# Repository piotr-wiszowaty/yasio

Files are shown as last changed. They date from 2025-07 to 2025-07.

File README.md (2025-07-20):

YASIO
=====

Yet another [Atari XL/XE](http://en.wikipedia.org/wiki/Atari_8-bit_family) SIO
floppy drive emulator - Yet-Another-SIO.

Features
--------

* Handles ATR and Atari executable files.
* Files stored on a micro-SD FAT32-formatted card.
* Works at speeds up to 115200 BPS.
* Controlled via a WWW browser via WiFi connection.
* Works in WiFi access point or station mode.

Hardware
--------

* Based on an ESP32-S3 devboard.
* Fits into a USB3 device enclosure.

Programming & Asembly
---------------------

Prerequisities:

* [xasm](https://github.com/pfusik/xasm)
* [foco65](https://github.com/piotr-wiszowaty/foco65)
* [PlatformIO](https://platformio.org)

0. Solder all of the components to the PCB.
1. Compile bootloader (optional): `bootloader/generate-bootloader.sh`.
2. Compile setup program: `setup/build.sh`.
3. Connect the device via USB-C cable to a PC (do not connect it to an Atari
   computer yet).
4. Flash the firmware by executing `pio run -e 0 -t upload` in `uc`
   subdirectory.
5. Disconnect the device from Atari computer; put the device in the enclosure.
   Three cutouts in the enclosure are required - for the USB socket, for the
   setup button and for the SIO cable. Note that the enclosure already has a
   hole allowing insertion/ejection of the SD card.

Usage
-----

### SD card preparation

Before turning on the device prepare an SD card - write configuration file
(`setup/yasio.conf`) and setup program (`setup/yasio_setup.xex`) to the root
directory of the SD card filesystem.

The configuration file contents may be prepared beforehand by using a text
editor or setup using the setup program. The setup program is 'inserted' into
`D1` drive by holding the setup button when turning on the device or by
pressing the setup button when the device is working and rebooting the Atari
computer.

### Configuration

Configuration file `yasio.conf` is an ASCII text file with LF-terminated lines.
Each line consists one configuration entry. Each entry starts with an entry key
followed by `:` character and (optional) entry value.
Available configuration entries and :

* `D1`, `D2`, `D3`, `D4` - path to file 'inserted' into appropriate drive;
  e.g.: `D1:demo/Drunk Chessboard.atr`
* `MO` - work mode; available values: `Station`, `AccessPoint`
* `AP` - WiFi access point parameters: SSID, password, IP-address/netmask;
  e.g.: `AP:My_ssid my_password 192.168.8.1/24`
* `ST` - WiFi station parameters: SSID, password; e.g.: `Some_ssid
  password123`; may occur multiple times

### WiFi

In access point mode the device advertises itself using the configured SSID and
password. The device address assigned is also taken from the configuration.

In station mode the configured access points are tried in the given order until
a connection to one succeeds. The assigned address may be retrieved by running
the setup program (pressing spacebar may be necessary to refresh the address
shown).

### LED indicator colors

* green - SD card initialization successful, WiFi initialization successful
* red - SD card initialization failure
* purple - failure connecting to WiFi access point

References
----------

The bootloader used for loading executable files is based on one
found in [Atari800](https://atari800.github.io/).

The code for controlling the LED on the devboard is by Espressif Systems
(Shanghai) CO LTD.

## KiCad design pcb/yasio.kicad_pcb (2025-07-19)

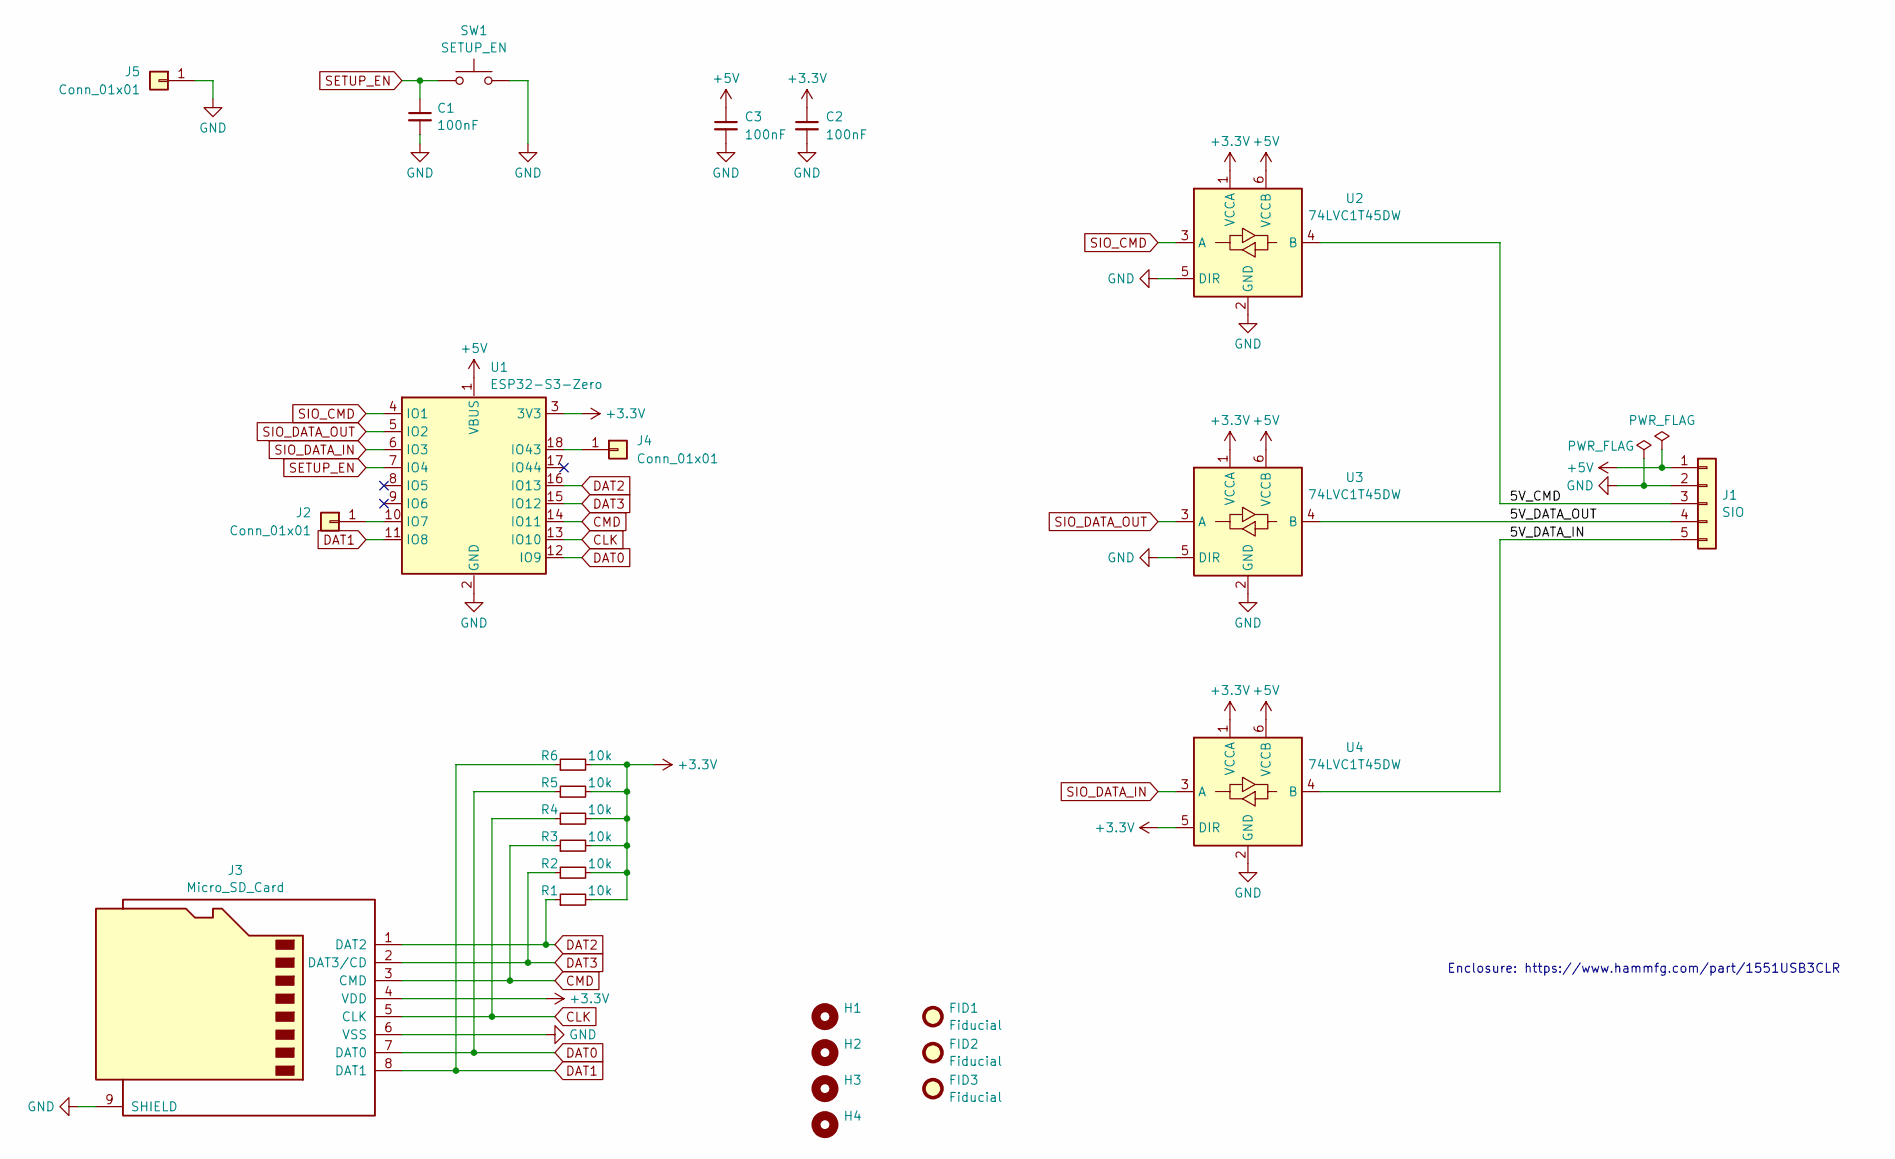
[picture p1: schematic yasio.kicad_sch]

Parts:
C1, C2, C3: 100nF; C_0805_2012Metric_Pad1.18x1.45mm_HandSolder
FID1, FID2, FID3: Fiducial; Fiducial_0.75mm_Mask1.5mm
H1, H2, H3, H4: MountingHole; MountingHole_2.2mm_M2
J1: SIO; PinHeader_1x05_P2.54mm_Vertical
J2, J4, J5: Conn_01x01; PinHeader_1x01_P2.54mm_Vertical
J3: Micro_SD_Card; microSD_HC_Hirose_DM3BT-DSF-PEJS
R1, R2, R3, R4, R5, R6: 10k; R_0805_2012Metric_Pad1.20x1.40mm_HandSolder
SW1: SETUP_EN; SW_Push_1P1T_NO_CK_KSC9xxGxxx
U1: ESP32-S3-Zero
U2, U3, U4: 74LVC1T45DW; SOT-363_SC-70-6_Handsoldering

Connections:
+3.3V: C2.1, J3.4 (VDD), R1.2, R2.2, R3.2, R4.2, R5.2, R6.2, U1.3 (3V3), U2.1 (VCCA), U3.1 (VCCA), U4.1 (VCCA), U4.5 (DIR)
+5V: C3.1, J1.1, U1.1 (VBUS), U2.6 (VCCB), U3.6 (VCCB), U4.6 (VCCB)
/5V_CMD: J1.3, U2.4 (B)
/5V_DATA_IN: J1.5, U4.4 (B)
/5V_DATA_OUT: J1.4, U3.4 (B)
CLK: J3.5 (CLK), R4.1, U1.13 (IO10)
CMD: J3.3 (CMD), R3.1, U1.14 (IO11)
DAT0: J3.7 (DAT0), R5.1, U1.12 (IO9)
DAT1: J3.8 (DAT1), R6.1, U1.11 (IO8)
DAT2: J3.1 (DAT2), R1.1, U1.16 (IO13)
DAT3: J3.2 (DAT3/CD), R2.1, U1.15 (IO12)
GND: C1.2, C2.2, C3.2, J1.2, J3.6 (VSS), J3.9 (SHIELD), J5.1, SW1.2, U1.2 (GND), U2.2 (GND), U2.5 (DIR), U3.2 (GND), U3.5 (DIR), U4.2 (GND)
unnamed: J2.1, U1.10 (IO7)
unnamed: J4.1, U1.18 (IO43)
SETUP_EN: C1.1, SW1.1, U1.7 (IO4)
SIO_CMD: U1.4 (IO1), U2.3 (A)
SIO_DATA_IN: U1.6 (IO3), U4.3 (A)
SIO_DATA_OUT: U1.5 (IO2), U3.3 (A)

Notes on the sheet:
Enclosure: https://www.hammfg.com/part/1551USB3CLR

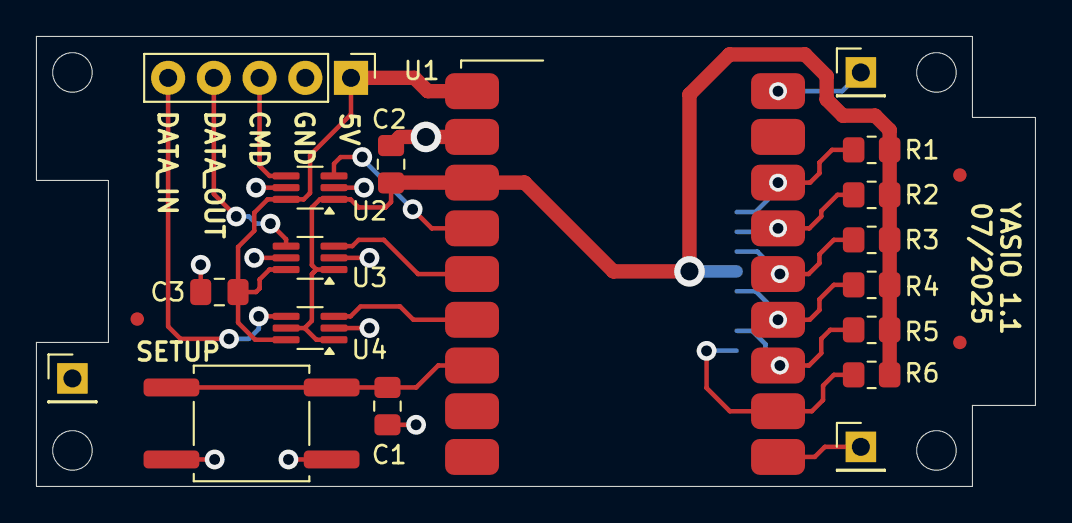
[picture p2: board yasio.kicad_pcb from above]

Board: 2 copper layers, 55.5 x 25.0 mm, 26 parts (1 on the bottom side), 18 nets.

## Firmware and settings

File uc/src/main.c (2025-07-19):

#include <stdio.h>
#include <stdarg.h>
#include <string.h>
#include <unistd.h>
#include "sdkconfig.h"
#include "freertos/FreeRTOS.h"
#include "freertos/task.h"
#include "freertos/event_groups.h"
#include "sys/socket.h"
#include "errno.h"
#include "arpa/inet.h"
#include "esp_chip_info.h"
#include "esp_flash.h"
#include "esp_system.h"
#include "esp_tls.h"
#include "esp_check.h"
#include "esp_wifi.h"
#include "esp_event.h"
#include "esp_log.h"
#include "esp_timer.h"
#include "esp_netif.h"
#include "register/soc/gpio_reg.h"
#include "register/soc/uart_reg.h"
#include "nvs_flash.h"
#include "esp_tls_crypto.h"
#include "esp_http_server.h"
#include "lwip/dhcp.h"
#include "lwip/err.h"
#include "lwip/sys.h"
#include "dhcpserver/dhcpserver.h"
#include "dhcpserver/dhcpserver_options.h"
#include "esp_vfs.h"
#include "esp_vfs_fat.h"
#include "sdmmc_cmd.h"
#include "driver/sdmmc_host.h"
#include "driver/uart.h"
#include "hungarian_wrappers.h"
#include "favicon.h"
#include "download_icon.h"
#include "eject_icon.h"
#include "insert_icon.h"
#include "mkdir_icon.h"
#include "new_image_icon.h"
#include "reload_icon.h"
#include "trash_icon.h"
#include "upload_icon.h"
#include "bootloader.h"
#include "bootloader_hs.h"
#include "driver/rmt_tx.h"
#include "led_strip_encoder.h"

#define ESP_MAXIMUM_RETRY			8
#define CONFIG_ESP_WPA3_SAE_PWE_HUNT_AND_PECK	1
#define CONFIG_ESP_WIFI_AUTH_WPA_WPA2_PSK	1

#if CONFIG_ESP_WPA3_SAE_PWE_HUNT_AND_PECK
#define ESP_WIFI_SAE_MODE	WPA3_SAE_PWE_HUNT_AND_PECK
#define EXAMPLE_H2E_IDENTIFIER	""
#elif CONFIG_ESP_WPA3_SAE_PWE_HASH_TO_ELEMENT
#define ESP_WIFI_SAE_MODE	WPA3_SAE_PWE_HASH_TO_ELEMENT
#define EXAMPLE_H2E_IDENTIFIER	CONFIG_ESP_WIFI_PW_ID
#elif CONFIG_ESP_WPA3_SAE_PWE_BOTH
#define ESP_WIFI_SAE_MODE	WPA3_SAE_PWE_BOTH
#define EXAMPLE_H2E_IDENTIFIER	CONFIG_ESP_WIFI_PW_ID
#endif

#if CONFIG_ESP_WIFI_AUTH_OPEN
#define ESP_WIFI_SCAN_AUTH_MODE_THRESHOLD WIFI_AUTH_OPEN
#elif CONFIG_ESP_WIFI_AUTH_WEP
#define ESP_WIFI_SCAN_AUTH_MODE_THRESHOLD WIFI_AUTH_WEP
#elif CONFIG_ESP_WIFI_AUTH_WPA_PSK
#define ESP_WIFI_SCAN_AUTH_MODE_THRESHOLD WIFI_AUTH_WPA_PSK
#elif CONFIG_ESP_WIFI_AUTH_WPA2_PSK
#define ESP_WIFI_SCAN_AUTH_MODE_THRESHOLD WIFI_AUTH_WPA2_PSK
#elif CONFIG_ESP_WIFI_AUTH_WPA_WPA2_PSK
#define ESP_WIFI_SCAN_AUTH_MODE_THRESHOLD WIFI_AUTH_WPA_WPA2_PSK
#elif CONFIG_ESP_WIFI_AUTH_WPA3_PSK
#define ESP_WIFI_SCAN_AUTH_MODE_THRESHOLD WIFI_AUTH_WPA3_PSK
#elif CONFIG_ESP_WIFI_AUTH_WPA2_WPA3_PSK
#define ESP_WIFI_SCAN_AUTH_MODE_THRESHOLD WIFI_AUTH_WPA2_WPA3_PSK
#elif CONFIG_ESP_WIFI_AUTH_WAPI_PSK
#define ESP_WIFI_SCAN_AUTH_MODE_THRESHOLD WIFI_AUTH_WAPI_PSK
#endif

#define WIFI_CONNECTED_BIT	BIT0
#define WIFI_FAIL_BIT		BIT1
#define WIFI_SCAN_DONE_BIT	BIT2
#define WIFI_DISCONNECTED_BIT	BIT3
#define WIFI_STA_STOP_BIT	BIT4
#define HTTP_QUERY_KEY_MAX_LEN	64

#define WIFI_SCAN_LIST_SIZE	10
#define CREDENTIALS_LIST_SIZE	15
#define YASIO_WIFI_MODE_STA	0x00
#define YASIO_WIFI_MODE_AP	0xff

#define AP_SSID			"tplink_859483"
#define AP_PASS			"tajne_859483"
#define AP_CHANNEL		1

#ifndef MIN
#define MIN(a, b)		(((a) < (b)) ? (a) : (b))
#endif

#define SETUP_SERVER_PORT	6777

#define DEBUG1_PIN		7
#define DEBUG2_PIN		43
#define SETUP_ENABLE_PIN	4

#define PIN_RMT_OUT		21
#define RESOLUTION_HZ		3333333

#define CMD_PIN	11
#define CLK_PIN	10
#define D0_PIN	9
#define D1_PIN	8
#define D2_PIN	13
#define D3_PIN	12

#define NOTIFICATION_CMD_LO		0
#define NOTIFICATION_CMD_HI		1
#define NOTIFICATION_ENABLE_SETUP	2
#define NOTIFICATION_TIMEOUT		3

#define SIO_UART_NUM		UART_NUM_1
#define SIO_CMD_PIN		1
#define SIO_UART_TXD_PIN	3
#define SIO_UART_RXD_PIN	2
#define SIO_BUFFER_SIZE		1024
#define ESP_INTR_FLAG_DEFAULT	0

#define F_OSC			1773447

#define DCMND_FORMAT_DISK		0x21
#define DCMND_FORMAT_MEDIUM		0x22
#define DCNMD_SEND_HIGH_SPEED_INDEX	0x3f
#define DCNMD_HAPPY_CONFIG		0x48
#define DCMND_READ_PERCOM		0x4e
#define DCMND_PUT_SECTOR		0x50
#define DCMND_READ_SECTOR		0x52
#define DCMND_READ_STATUS		0x53
#define DCMND_WRITE_SECTOR		0x57
#define DCMND_GET_IP_ADDRESS		0xf0
#define DCMND_GET_NETWORK		0xf1
#define DCMND_SELECT_NETWORK		0xf2
#define DCMND_GET_WIFI_MODE		0xf3
#define DCMND_SCAN_NETWORKS		0xf4
#define DCMND_GET_AP_PARAMETERS		0xf5
#define DCMND_SET_AP			0xf6
#define DCMND_GET_CHUNK			0xf8
#define DCMND_GET_NEXT_CHUNK		0xf9

#define DRIVE_TYPE_ATR		1
#define DRIVE_TYPE_XEX		2
#define ATR_HEADER_SIZE		16
#define BOOT_SECTOR_SIZE	128
#define BOOT_PATH_OFFSET	0x1c
#define BOOT_PATH_LENGTH	30
#define N_HS_INDICES		9

#define MOUNT_POINT		"/sdcard"
#define YASIO_CONFIG_FNAME	"yasio.conf"
#define YASIO_SETUP_FNAME	"yasio_setup.xex"

struct Drive {
	char path[256];
	uint8_t *buffer;
	int type;
	/* ATR */
	uint32_t total_paragraphs;
	uint32_t sector_size;
	int write_protected;
	uint32_t total_sectors;
	uint32_t last_read_sector;
	uint32_t total_tracks;
	uint32_t sectors_per_track;
	uint32_t size;
	/* COM/EXE/XEX */
	uint32_t chunk_offset;
	uint32_t prev_chunk_size;
};

struct ResponseContext {
	httpd_req_t *req;
	char *buf;
	int buf_size;
	int offset;
};

struct HSIDescriptor {
	int val;
	char *str;
	char *kbps;
};

struct Credentials {
	char ssid[64];
	char pass[64];
};

static const char *TAG = "yasio";

static esp_netif_t *sta_netif;
static esp_netif_t *ap_netif;
static EventGroupHandle_t s_wifi_event_group;
static uint16_t ap_number = WIFI_SCAN_LIST_SIZE;
static wifi_ap_record_t ap_info[WIFI_SCAN_LIST_SIZE];
static uint16_t ap_count = 0;
static struct Credentials credentials[CREDENTIALS_LIST_SIZE];
static char ap_ssid[64];
static char ap_password[64];
static char ap_ip[32];

static SemaphoreHandle_t connection_gate;
static int s_retry_num = 0;
static httpd_handle_t server = NULL;
static char ssid_connected[64];
static char ip_address[16];
static char setup_server_ip[16];

static TaskHandle_t sio_task_handle = NULL;
static struct Drive drives[4];
static esp_timer_handle_t timeout_timer;

static uint32_t high_speed_index = 40;	// default: 18866 bps

static uint8_t led_pixel[3];
static rmt_channel_handle_t led_chan = NULL;
static rmt_tx_channel_config_t tx_chan_config = {
	.clk_src = RMT_CLK_SRC_DEFAULT,
	.gpio_num = PIN_RMT_OUT,
	.mem_block_symbols = 64,
	.resolution_hz = RESOLUTION_HZ,
	.trans_queue_depth = 4,
	.flags.invert_out = false,
};
static rmt_encoder_handle_t led_encoder = NULL;
static rmt_transmit_config_t tx_config = {
	.loop_count = 0,
};

const char *main_view_header =
"<!DOCTYPE html>\n"
"<html>\n"
" <head>\n"
"  <style>.direntry{font-family:courier} .img-size img {width: 16px; height: 16px} .sep-col td {width: 60 px}</style>\n"
" </head>\n"
" <body>\n";
const char *main_view_full_drive_entry =
"  <div>\n"
"   <table>\n"
"    <tr class='direntry'>\n"
"     <td>\n"
"      <form method='post' action='$uri'>\n"
"       <button class='img-size'><img src='/eject_icon.png' alt='Eject'/></button>\n"
"       <input type='hidden' name='op' value='eject'/>\n"
"       <input type='hidden' name='drive' value='$1'/>\n"
"      </form>\n"
"     </td>\n"
"     <td>D$1:</td>\n"
"     <td>$2</td>\n"
"    </tr>\n"
"   </table>\n"
"  </div>";
const char *main_view_empty_drive_entry =
"  <div>\n"
"    <table>\n"
"      <tr class='direntry'>\n"
"       <td><button class='img-size' disabled><img src='/eject_icon.png' alt='Eject'/></button></td>\n"
"       <td>D$1:</td>\n"
"       <td>(empty)</td>\n"
"      </tr>\n"
"    </table>\n"
"  </div>\n";
const char *main_view_reload_setup =
"  <div>\n"
"   <form method='post' action='$uri'>\n"
"    <input type='hidden' name='op' value='reload'/>\n"
"    <button class='img-size'><img src='/reload_icon.png' alt='Reload'/></button>\n"
"   </form>\n"
"  </div>\n";
const char *main_view_save_state =
"  <div>\n"
"    <form method='post' action='$uri'>\n"
"      <input type='hidden' name='op' value='save'/>\n"
"      <button>Save state</button>\n"
"    </form>\n"
"  </div>\n";
const char *main_view_hsi_head =
"  <div>\n"
"   <form method='post' action='$uri'>High Speed Index:\n"
"    <select name='hsi' id='hsi'>\n";
const char *main_view_hsi_entry =
"     <option value='$1'$2>$1 ($3 kbps)</option>\n";
const char *main_view_hsi_tail =
"    </select>\n"
"    <input type='hidden' name='op' value='selhsi'/>\n"
"    <button type='submit'>Select</button>\n"
"   </form>\n"
"  </div>\n";
const char *main_view_mkdir =
"  <div>\n"
"   <form method='post' action='$uri'>\n"
"    <input type='text' placeholder='Directory name' id='dirname' name='dirname' required/>\n"
"    <input type='hidden' name='op' value='mkdir'/>\n"
"    <button class='img-size'><img src='/mkdir_icon.png' alt='Make dir'/></button>\n"
"   </form>\n"
"  </div>\n";
const char *main_view_upload_file =
"  <div>\n"
"   <form method='post' enctype='multipart/form-data' action='$uri'>\n"
"    <input type='file' id='upfile' name='write-file'/>\n"
"    <button class='img-size'><img src='/upload_icon.png' alt='Upload'/></button>\n"
"   </form>\n"
"  </div>\n";
const char *main_view_create_empty_disk =
"  <div>\n"
"   <form method='post' action='$uri'>\n"
"    New image:<input type='text' placeholder='File name' id='filename' name='filename' required/>\n"
"    <input type='hidden' name='op' value='mkimg'/>\n"
"    <select name='density' id='density'>\n"
"     <option value='SD'>SD (90k)</option>\n"
"     <option value='ED'>ED (130k)</option>\n"
"     <option value='DD'>DD (180k)</option>\n"
"     <option value='QD'>QD (360k)</option>\n"
"     <option value='HD'>HD (720k)</option>\n"
"    </select>\n"
"    <button class='img-size'><img src='/new_image_icon.png' alt='New image'/></button>\n"
"   </form>\n"
"  </div>\n";
const char *main_view_dirlist_head =
"  <table>\n";
const char *main_view_dirlist_parent =
"   <tr class='direntry'>\n"
"    <td></td>\n"
"    <td></td>\n"
"    <td></td>\n"
"    <td></td>\n"
"    <td></td>\n"
"    <td></td>\n"
"    <td></td>\n"
"    <td></td>\n"
"    <td><a href='$1'>Parent directory</a></td>\n"
"   </tr>";
const char *main_view_dirlist_dir =
"   <tr class='direntry'>\n"
"    <td></td>\n"
"    <td></td>\n"
"    <td></td>\n"
"    <td></td>\n"
"    <td></td>\n"
"    <td>\n"
"     <form method='post' action='$uri'>\n"
"      <button class='img-size'><img src='/trash_icon.png' alt='Delete'/></button>\n"
"      <input type='hidden' name='op' value='rmdir'/>\n"
"      <input type='hidden' name='dirname' value='$1'/>\n"
"     </form>\n"
"    </td>\n"
"    <td></td>\n"
"    <td class='sep-col'></td>\n"
"    <td class='text'><a href='$uri1/$1'>$1/</a></td>\n"
"   </tr>\n";
const char *main_view_dirlist_file =
"   <tr class='direntry'>\n"
"    <td>\n"
"     <form method='post' action='$uri1/$1'>\n"
"      <input type='hidden' name='op' value='insert'/>\n"
"      <input type='hidden' name='drive' value='1'/>\n"
"      <button class='img-size'><img src='/insert_icon.png' alt='Insert D1:'/></button>\n"
"     </form>\n"
"    </td>\n"
"    <td>\n"
"     <form method='post' action='$uri1/$1'>\n"
"      <input type='hidden' name='op' value='insert'/>\n"
"      <input type='hidden' name='drive' value='2'/>\n"
"      <button class='img-size'><img src='/insert_icon.png' alt='Insert D2:'/></button>\n"
"     </form>\n"
"    </td>\n"
"    <td>\n"
"     <form method='post' action='$uri1/$1'>\n"
"      <input type='hidden' name='op' value='insert'/>\n"
"      <input type='hidden' name='drive' value='3'/>\n"
"      <button class='img-size'><img src='/insert_icon.png' alt='Insert D3:'/></button>\n"
"     </form>\n"
"    </td>\n"
"    <td>\n"
"     <form method='post' action='$uri1/$1'>\n"
"      <input type='hidden' name='op' value='insert'/>\n"
"      <input type='hidden' name='drive' value='4'/>\n"
"      <button class='img-size'><img src='/insert_icon.png' alt='Insert D4:'/></button>\n"
"     </form>\n"
"    </td>\n"
"    <td>\n"
"     <a href='$uri1/$1?op=download' download='$1'><button class='img-size'><img src='/download_icon.png' alt='Download'/></button></a>\n"
"    </td>\n"
"    <td>\n"
"     <form method='post' action='$uri'>\n"
"      <input type='hidden' name='op' value='rmfile'/>\n"
"      <input type='hidden' name='filename' value='$1'/>\n"
"      <button class='img-size'><img src='/trash_icon.png' alt='Delete'/></button>\n"
"     </form>\n"
"    </td>\n"
"    <td class='text'>$2</td>\n"
"    <td class='sep-col'></td>\n"
"    <td class='text'>$1</td>\n"
"   </tr>\n";
const char *main_view_dirlist_tail =
"  </table>\n";
const char *main_view_tail =
" </body>\n"
"</html>";

const char *error_view =
"<!DOCTYPE html>\n"
"<html>\n"
" <head></head>\n"
" <body>\n"
"  <div>$1</div>\n"
"  <button onclick=\"location.href='$uri'\">Go back</button>\n"
" </body>\n"
"</html>";

const struct HSIDescriptor hsi_lut[N_HS_INDICES] = {
	{40, "40", "18.9"},
	{16, "16", "38.5"},
	{10, "10", "52.5"},
	{9, "9", "55.4"},
	{8, "8", "59.1"},
	{6, "6", "68.2"},
	{4, "4", "80.4"},
	{2, "2", "98.5"},
	{1, "1", "110.8"}
};

static void set_rgb(uint8_t r, uint8_t g, uint8_t b)
{
	led_pixel[0] = r;
	led_pixel[1] = g;
	led_pixel[2] = b;
	ESP_ERROR_CHECK(rmt_transmit(led_chan, led_encoder, led_pixel, sizeof(led_pixel), &tx_config));
}

static int load_atr(int drive, int size)
{
	uint8_t *header = drives[drive].buffer;

	if (header[0] != 0x96 || header[1] != 0x02) {
		return -1;
	}

	drives[drive].total_paragraphs = ((uint32_t) header[2] & 0xff) | (((uint32_t) header[3] & 0xff) << 8) | (((uint32_t) header[6] & 0xff) << 16);
	drives[drive].sector_size = ((uint32_t) header[4] & 0xff) | (((uint32_t) header[5] & 0xff) << 8);
	drives[drive].write_protected = (header[15] & 1) == 1;
	if (drives[drive].sector_size == 128) {
		drives[drive].total_sectors = 16*drives[drive].total_paragraphs / drives[drive].sector_size;
	} else if (drives[drive].sector_size == 512) {
		drives[drive].total_sectors = 16*drives[drive].total_paragraphs / drives[drive].sector_size;
	} else if (drives[drive].sector_size == 256) {
		if ((drives[drive].total_paragraphs & 0x0f) == 0x00) {
			drives[drive].total_sectors = 16*drives[drive].total_paragraphs / drives[drive].sector_size;
		} else if ((drives[drive].total_paragraphs & 0x0f) == 0x08) {
			drives[drive].total_sectors = 16*(drives[drive].total_paragraphs + 24) / drives[drive].sector_size;
		}
	}
	if (drives[drive].total_sectors % 80 == 0) {
		drives[drive].total_tracks = 80;
	} else {
		drives[drive].total_tracks = 40;
	}
	drives[drive].sectors_per_track = drives[drive].total_sectors / drives[drive].total_tracks;
	drives[drive].type = DRIVE_TYPE_ATR;

	drives[drive].size = size;

	return 0;
}

static int load_xex(uint32_t size)
{
	uint8_t *header = drives[0].buffer;
	int l = MIN(BOOT_PATH_LENGTH, strlen(drives[0].path));
	int i;

	if (header[0] != 0xff || header[1] != 0xff) {
		return -1;
	}

	for (i = 0; i < l; i++) {
		bootloader[BOOT_PATH_OFFSET+i] = drives[0].path[i];
		bootloader_hs[BOOT_PATH_OFFSET+i] = drives[0].path[i];
	}
	bootloader[BOOT_PATH_OFFSET+i] = 0x9b;
	bootloader_hs[BOOT_PATH_OFFSET+i] = 0x9b;

	drives[0].type = DRIVE_TYPE_XEX;
	drives[0].size = size;
	drives[0].chunk_offset = 2;
	drives[0].prev_chunk_size = 0;

	uart_set_baudrate(SIO_UART_NUM, (F_OSC/2) / (7 + 40));

	return 0;
}

static int ends_with(char *s, char *postfix)
{
	int i;

	for (i = 0; s[i]; i++);
	return i >= strlen(postfix) && !strcmp(postfix, s + i - strlen(postfix));
}

static esp_err_t insert_image(char *path, int drive)
{
	FILE *fp;
	char *f_buf;
	int f_buf_len;

	fp = fopen(path, "rb");
	if (fp == NULL) {
		ESP_LOGE(TAG, "fopen error '%s'", path);
		return ESP_FAIL;
	}
	fseek(fp, 0, SEEK_END);
	f_buf_len = ftell(fp);
	fseek(fp, 0, SEEK_SET);
	f_buf = malloc(f_buf_len);
	if (f_buf == NULL) {
		ESP_LOGE(TAG, "malloc %d failed", f_buf_len);
		fclose(fp);
		return ESP_FAIL;
	}
	fread(f_buf, 1, f_buf_len, fp);
	fclose(fp);

	ESP_LOGI(TAG, "inserting file '%s' (%d) into D%d", path, f_buf_len, drive + 1);

	if (drive >= 0 && drive <= 3) {
		if (drives[drive].buffer != NULL) {
			free(drives[drive].buffer);
		}
		drives[drive].buffer = (uint8_t *) f_buf;
		strcpy(drives[drive].path, path + sizeof(MOUNT_POINT));
		if ((ends_with(path, ".atr") || ends_with(path, ".ATR")) && load_atr(drive, f_buf_len) == 0) {
			ESP_LOGI(TAG, "file inserted");
		} else if ((ends_with(path, ".xex") || ends_with(path, ".XEX") || ends_with(path, ".com") || ends_with(path, ".COM"))
				&& drive == 0 && load_xex(f_buf_len) == 0) {
			ESP_LOGI(TAG, "file inserted");
		} else {
			ESP_LOGE(TAG, "file insertion failed");
			free(drives[drive].buffer);
			drives[drive].path[0] = 0;
			// TODO: show error message
		}
		return ESP_OK;
	} else {
		return ESP_FAIL;
	}
}

static void sort_insert(char **names, char *name)
{
	int n;
	char *tmp;

	if (names[0] == NULL) {
		names[0] = name;
		names[1] = NULL;
		return;
	}
	for (n = 0; names[n] != NULL; n++);
	names[n+1] = NULL;
	names[n] = name;
	for (; strcmp(names[n], names[n-1]) < 0; n--) {
		tmp = names[n];
		names[n] = names[n-1];
		names[n-1] = tmp;
		if (n == 1) break;
	}
}

static void build_effective_path(httpd_req_t *req, char *name, char *path)
{
	char *dest;
	int i;

	strcpy(path, MOUNT_POINT);

	if (strcmp(req->uri, "/")) {
		strcat(path, req->uri);
	}

	dest = strcat(path, "/");

	for (dest = path; *dest; dest++);
	i = 0;
	while (name[i]) {
		if (name[i] == '+') {
			*dest++ = ' ';
			i++;
		} else if (!strncmp(name + i, "%2B", 3)) {
			*dest++ = '+';
			i += 3;
		} else if (!strncmp(name + i, "%2C", 3)) {
			*dest++ = ',';
			i += 3;
		} else if (!strncmp(name + i, "%28", 3)) {
			*dest++ = '(';
			i += 3;
		} else if (!strncmp(name + i, "%29", 3)) {
			*dest++ = ')';
			i += 3;
		} else {
			*dest++ = name[i++];
		}
	}
	*dest = 0;
}

static void add_response_data(struct ResponseContext *ctx, const char *data, ...)
{
	int i;
	char *src = (char *) data;
	char *src_stack = NULL;
	va_list ap;
	char *args[4];
	int n_args = 0;

	va_start(ap, data);

	while (*src || src_stack != NULL) {
		if (*src == 0) {
			src = src_stack;
			src_stack = NULL;
		}
		if (*src == '$') {
			if (!strncmp(src + 1, "uri1", 4)) {
				if (strcmp(ctx->req->uri, "/")) {
					src_stack = src + 5;
					src = (char *) ctx->req->uri;
				} else {
					src = src + 5;
				}
			} else if (!strncmp(src + 1, "uri", 3)) {
				src_stack = src + 4;
				src = (char *) ctx->req->uri;
			} else {
				for (i = src[1] - '0'; n_args < i; n_args++) {
					args[n_args] = va_arg(ap, char *);
				}
				src_stack = src + 2;
				src = args[i - 1];
			}
			if (*src == 0) {			/* zero-length argument => skip it immediately */
				src = src_stack;
				src_stack = NULL;
			}
		}
		ctx->buf[ctx->offset++] = *src++;
		if (ctx->offset == ctx->buf_size) {
			httpd_resp_send_chunk(ctx->req, ctx->buf, ctx->offset);
			ctx->offset = 0;
		}
	}

	va_end(ap);
}
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
void app_main()
{
	wifi_mode_t wifi_mode;
	int i;

	for (i = 0; i < 4; i++) {
		drives[i].path[0] = 0;
		drives[i].buffer = NULL;
	}

	gpio_set_direction(DEBUG1_PIN, GPIO_MODE_OUTPUT);
	gpio_set_level(DEBUG1_PIN, 0);
	gpio_set_direction(DEBUG2_PIN, GPIO_MODE_OUTPUT);
	gpio_set_level(DEBUG2_PIN, 0);

	gpio_input_enable(SETUP_ENABLE_PIN);
	gpio_set_pull_mode(SETUP_ENABLE_PIN, GPIO_PULLUP_ONLY);

	//info();
	ESP_ERROR_CHECK(nvs_flash_init());

	ESP_ERROR_CHECK(rmt_new_tx_channel(&tx_chan_config, &led_chan));
	ESP_ERROR_CHECK(rmt_new_led_strip_encoder(&led_encoder));
	ESP_ERROR_CHECK(rmt_enable(led_chan));
	set_rgb(0x00, 0x00, 0x00);

	if (init_sdcard() != ESP_OK) {
		set_rgb(16, 0, 0);
		return;
	}
	strcpy(ap_ssid, "yasio");
	strcpy(ap_password, "yasio6502");
	strcpy(ap_ip, "192.168.4.1/24");
	load_wifi_config(&wifi_mode);

	if (gpio_get_level(SETUP_ENABLE_PIN) == 0) {
		ESP_LOGI(TAG, "inserting setup program");
		insert_image(MOUNT_POINT "/" YASIO_SETUP_FNAME, 0);
	} else {
		ESP_LOGI(TAG, "restoring state");
		load_drive_state();
	}

	connection_gate = semaphore_create_binary();
	open_gate("init");

	create_task_pinned_to_core(sio_task, "sio", 6144, NULL, 10, &sio_task_handle, 1);

	common_wifi_init();
	if (wifi_mode == WIFI_MODE_STA) {
		wifi_switch(WIFI_MODE_STA, NULL, NULL);
	} else if (wifi_mode == WIFI_MODE_AP) {
		wifi_switch(WIFI_MODE_AP, ap_ssid, ap_password);
	}
}

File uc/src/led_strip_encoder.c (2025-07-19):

/*
 * SPDX-FileCopyrightText: 2021-2022 Espressif Systems (Shanghai) CO LTD
 *
 * SPDX-License-Identifier: Apache-2.0
 */

#include "esp_check.h"
#include "led_strip_encoder.h"

static const char *TAG = "led_encoder";

typedef struct {
	rmt_encoder_t base;
	rmt_encoder_t *bytes_encoder;
	rmt_encoder_t *copy_encoder;
	int state;
	rmt_symbol_word_t reset_code;
} rmt_led_strip_encoder_t;

static size_t rmt_encode_led_strip(rmt_encoder_t *encoder, rmt_channel_handle_t channel, const void *primary_data, size_t data_size, rmt_encode_state_t *ret_state)
{
	rmt_led_strip_encoder_t *led_encoder = __containerof(encoder, rmt_led_strip_encoder_t, base);
	rmt_encoder_handle_t bytes_encoder = led_encoder->bytes_encoder;
	rmt_encoder_handle_t copy_encoder = led_encoder->copy_encoder;
	rmt_encode_state_t session_state = RMT_ENCODING_RESET;
	rmt_encode_state_t state = RMT_ENCODING_RESET;
	size_t encoded_symbols = 0;
	switch (led_encoder->state) {
		case 0: // send reset code
			encoded_symbols += copy_encoder->encode(copy_encoder, channel, &led_encoder->reset_code,
					sizeof(led_encoder->reset_code), &session_state);
			if (session_state & RMT_ENCODING_COMPLETE) {
				led_encoder->state = 1;
			}
			if (session_state & RMT_ENCODING_MEM_FULL) {
				state |= RMT_ENCODING_MEM_FULL;
				goto out; // yield if there's no free space for encoding artifacts
			}
			// fall-through
		case 1: // send RGB data
			encoded_symbols += bytes_encoder->encode(bytes_encoder, channel, primary_data, data_size, &session_state);
			if (session_state & RMT_ENCODING_COMPLETE) {
				led_encoder->state = RMT_ENCODING_RESET; // back to the initial encoding session
				state |= RMT_ENCODING_COMPLETE;
			}
			if (session_state & RMT_ENCODING_MEM_FULL) {
				state |= RMT_ENCODING_MEM_FULL;
				goto out; // yield if there's no free space for encoding artifacts
			}
			// fall-through
	}
out:
	*ret_state = state;
	return encoded_symbols;
}

static esp_err_t rmt_del_led_strip_encoder(rmt_encoder_t *encoder)
{
	rmt_led_strip_encoder_t *led_encoder = __containerof(encoder, rmt_led_strip_encoder_t, base);
	rmt_del_encoder(led_encoder->bytes_encoder);
	rmt_del_encoder(led_encoder->copy_encoder);
	free(led_encoder);
	return ESP_OK;
}

static esp_err_t rmt_led_strip_encoder_reset(rmt_encoder_t *encoder)
{
	rmt_led_strip_encoder_t *led_encoder = __containerof(encoder, rmt_led_strip_encoder_t, base);
	rmt_encoder_reset(led_encoder->bytes_encoder);
	rmt_encoder_reset(led_encoder->copy_encoder);
	led_encoder->state = RMT_ENCODING_RESET;
	return ESP_OK;
}

esp_err_t rmt_new_led_strip_encoder(rmt_encoder_handle_t *ret_encoder)
{
	esp_err_t ret = ESP_OK;
	rmt_led_strip_encoder_t *led_encoder = NULL;
	ESP_GOTO_ON_FALSE(ret_encoder, ESP_ERR_INVALID_ARG, err, TAG, "invalid argument");
	led_encoder = rmt_alloc_encoder_mem(sizeof(rmt_led_strip_encoder_t));
	ESP_GOTO_ON_FALSE(led_encoder, ESP_ERR_NO_MEM, err, TAG, "no mem for led strip encoder");
	led_encoder->base.encode = rmt_encode_led_strip;
	led_encoder->base.del = rmt_del_led_strip_encoder;
	led_encoder->base.reset = rmt_led_strip_encoder_reset;
	rmt_bytes_encoder_config_t bytes_encoder_config = {
		.bit0 = {
			.level0 = 1,
			.duration0 = 1,	// 300 ns
			.level1 = 0,
			.duration1 = 3,	// 900 ns
		},
		.bit1 = {
			.level0 = 1,
			.duration0 = 2,	// 600 ns
			.level1 = 0,
			.duration1 = 2,	// 600 ns
		},
		.flags.msb_first = 1	// WS2812 transfer bit order: G7...G0R7...R0B7...B0
	};
	ESP_GOTO_ON_ERROR(rmt_new_bytes_encoder(&bytes_encoder_config, &led_encoder->bytes_encoder), err, TAG, "create bytes encoder failed");
	rmt_copy_encoder_config_t copy_encoder_config = {};
	ESP_GOTO_ON_ERROR(rmt_new_copy_encoder(&copy_encoder_config, &led_encoder->copy_encoder), err, TAG, "create copy encoder failed");

	uint32_t reset_ticks = 167;		// 50 us
	led_encoder->reset_code = (rmt_symbol_word_t) {
		.level0 = 0,
		.duration0 = reset_ticks/2,
		.level1 = 0,
		.duration1 = reset_ticks/2,
	};
	*ret_encoder = &led_encoder->base;
	return ESP_OK;
err:
	if (led_encoder) {
		if (led_encoder->bytes_encoder) {
			rmt_del_encoder(led_encoder->bytes_encoder);
		}
		if (led_encoder->copy_encoder) {
			rmt_del_encoder(led_encoder->copy_encoder);
		}
		free(led_encoder);
	}
	return ret;
}

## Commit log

2025-07-19 Add PCB design files
    [yasio.kicad_pcb, yasio.kicad_sch]
2025-07-19 Add PCB CAM files
    [yasio-B_Cu.gbr, yasio-B_Mask.gbr, yasio-Edge_Cuts.gbr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]
